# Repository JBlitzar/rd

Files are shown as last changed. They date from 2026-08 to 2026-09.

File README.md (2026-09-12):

# rd

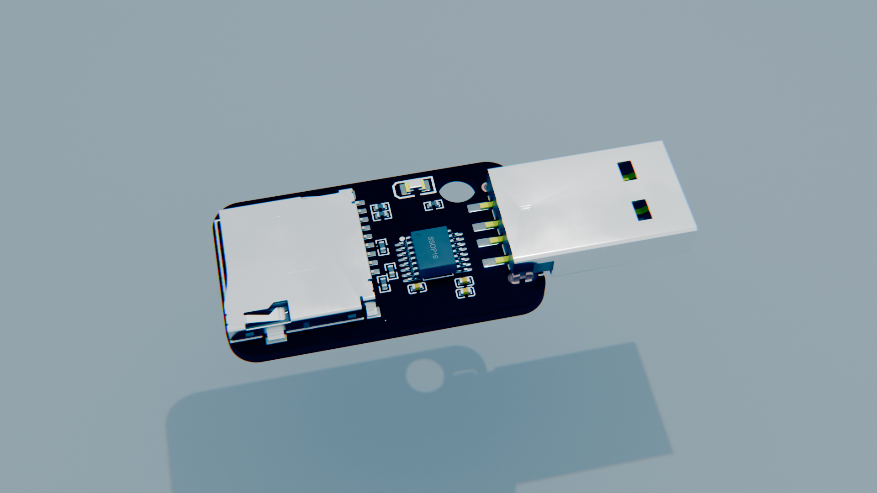
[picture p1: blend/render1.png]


microSD card reader. it exposes microSD cards as a block device that you can read and write to!

Features:
 - dead-simple schematic thanks to the GL823K chip
 - green status LED for activity
 - 4mm keychain hole
 - supports USB 2.0 HS and microSD HS. This means up to 25 MB/s ! 

I made this project because I needed a project scoped to be able to speedrun in 36 hours wall-clock and very little actual working time. It grants me utility-- this way I can read and write to microSD cards super easily in a small form factor, using a dongle I created!! I think microSD cards are uniquely very versatile. There are ones with industrially-rated durability. There are ones that go up to 2TB. There are ones that are so dirt-cheap they cost only a little bit more than the raw NAND inside them. Also, this project unlocks a new ASIC for me that I haven't used before.  

| |  |
| --- | --- |
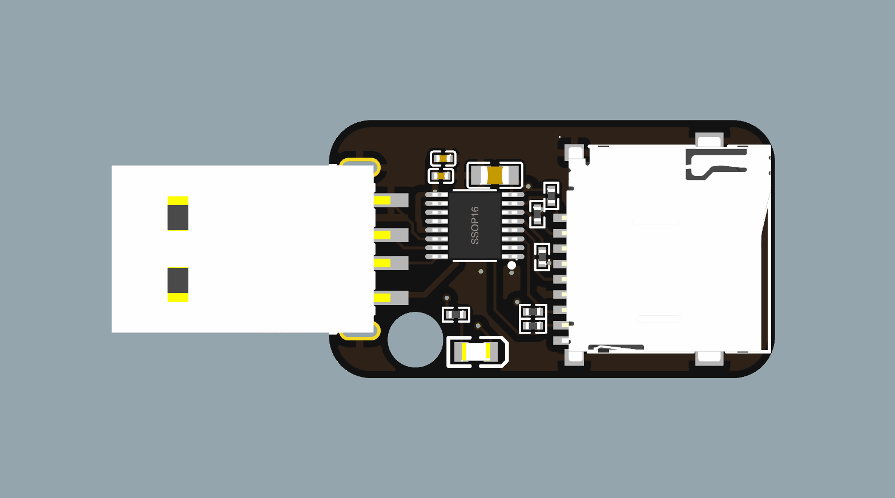
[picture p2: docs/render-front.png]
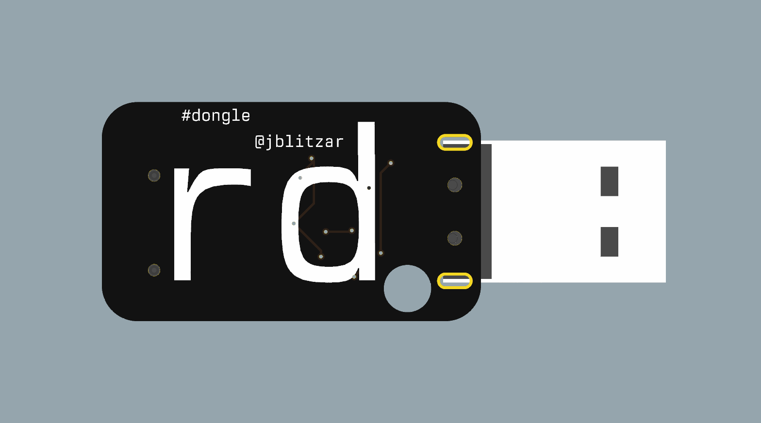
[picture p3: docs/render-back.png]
|  |  |

## Schematic

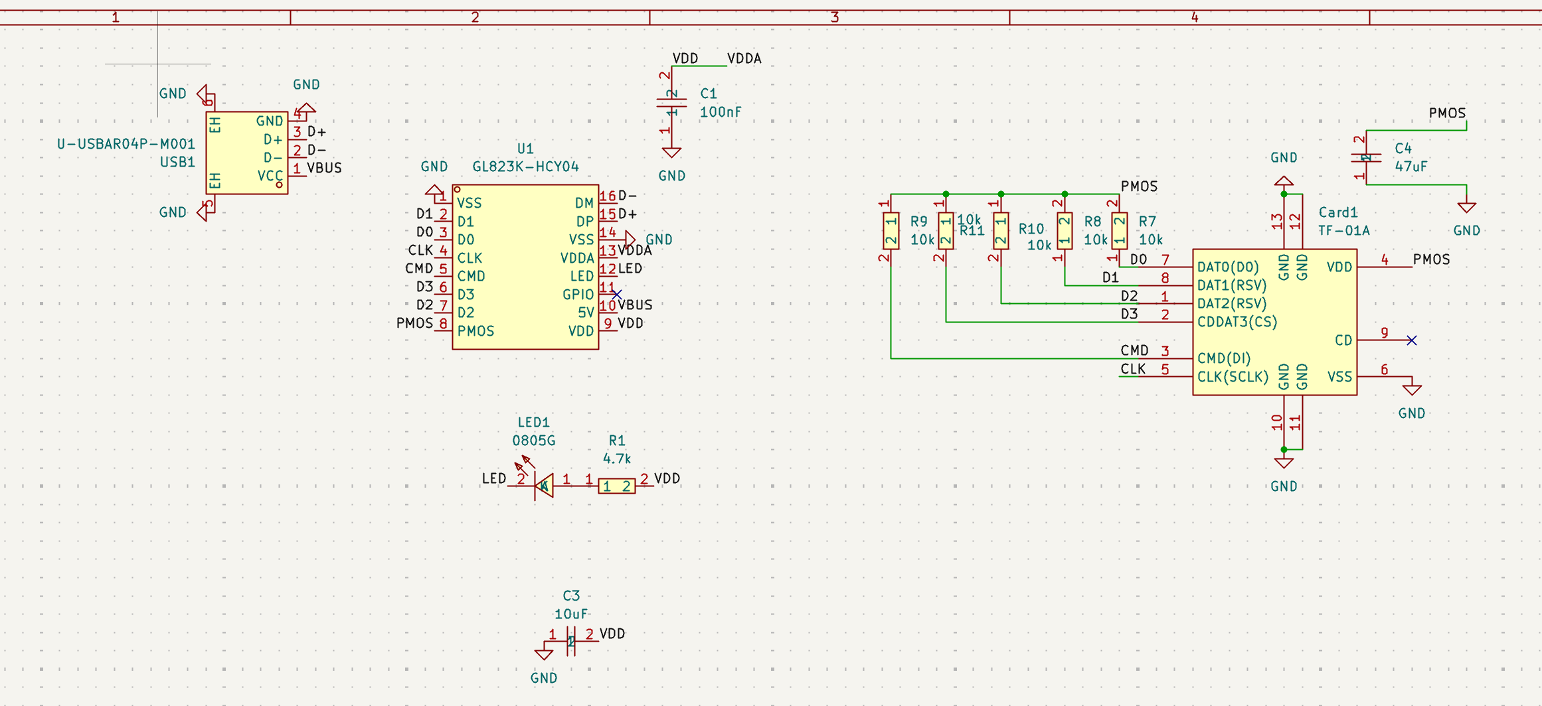
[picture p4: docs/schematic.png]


## PCB

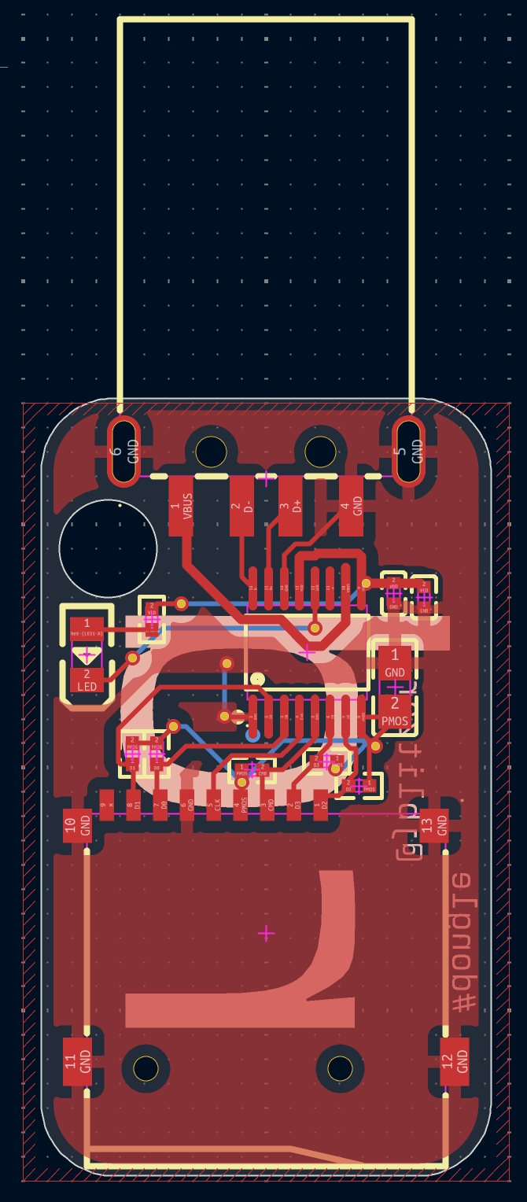
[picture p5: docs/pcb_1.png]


## Production outputs like gerbers

Find them in [PCB/rd/production](PCB/rd/production)!

## BOM

Order by uploading the fabrication outputs (linked above) to jlcpcb!

|Item |Cost |Notes |
|---|-----|---|
|5x PCB (MOQ) |2.0  |order off of JLCONE desktop to save two dollars instead of it costing $4|
|2x PCBA (MOQ)|24.15| |
|Shipping |3.3  |Shipping special offer, otherwise costs 7 |
|Total |29.45| |

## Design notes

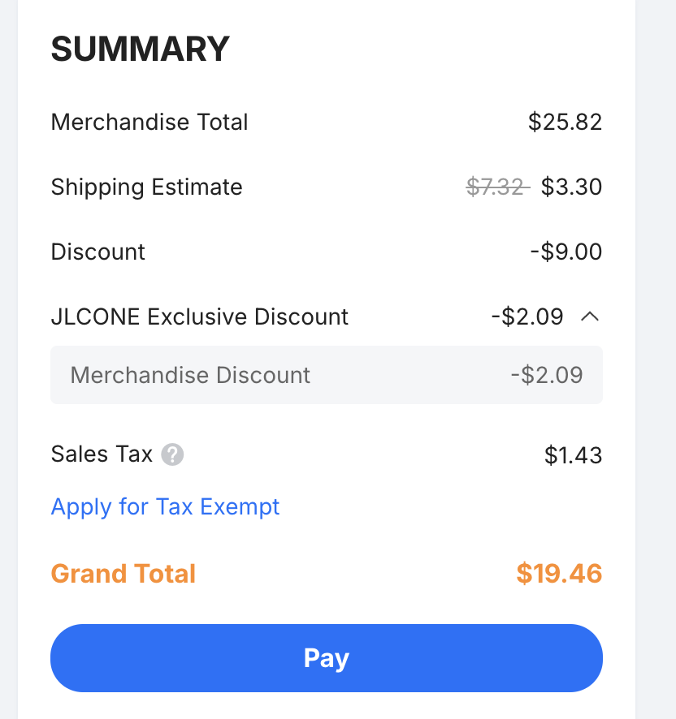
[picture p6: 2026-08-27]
docs/cart.png

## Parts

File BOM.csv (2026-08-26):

Item | Cost | Notes
5x PCB (MOQ) | 2.1 | order off of JLCONE desktop to save two dollars instead of it costing $4
2x PCBA (MOQ) | 23.82
Shipping | 3.3 | Shipping special offer, otherwise costs 7
Total | 29.22

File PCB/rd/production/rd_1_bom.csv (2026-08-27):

Designator | Footprint | Quantity | Value | LCSC Part #
C1 | C0402 | 1 | 100nF | C1525
C3 | C0402 | 1 | 10uF | C15525
C4 | C0805 | 1 | 47uF | C16780
CARD1 | TF-SMD_TF-01A | 1 | TF-01A | C91145
LED1 | LED0805-R-RD | 1 | 0805G | C2297
R1 | R0402 | 1 | 4.7k | C25900
R10, R11, R7, R8, R9 | R0402 | 5 | 10k | C25744
U1 | SSOP-16_L4.9-W3.9-P0.64-LS6.0-BL | 1 | GL823K-HCY04 | C284879
USB1 | USB-SMD_KH-USB-AM-4P-CB | 1 | U-USBAR04P-M001 | C386752

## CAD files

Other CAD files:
blend/rd.blend

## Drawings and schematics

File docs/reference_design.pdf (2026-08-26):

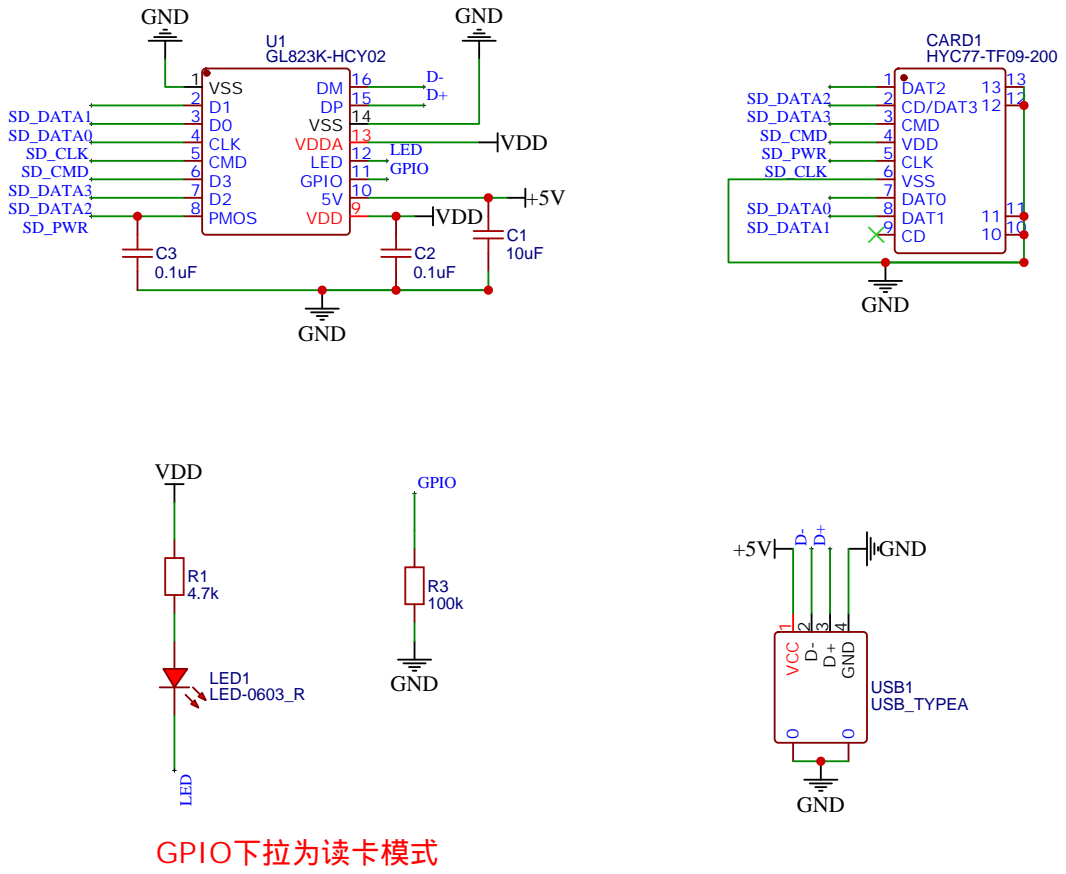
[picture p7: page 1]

GL823K-HCY02
5V 10 GPIO 11 LED 12 VDDA 13 VSS 14 DP 15 DM 16

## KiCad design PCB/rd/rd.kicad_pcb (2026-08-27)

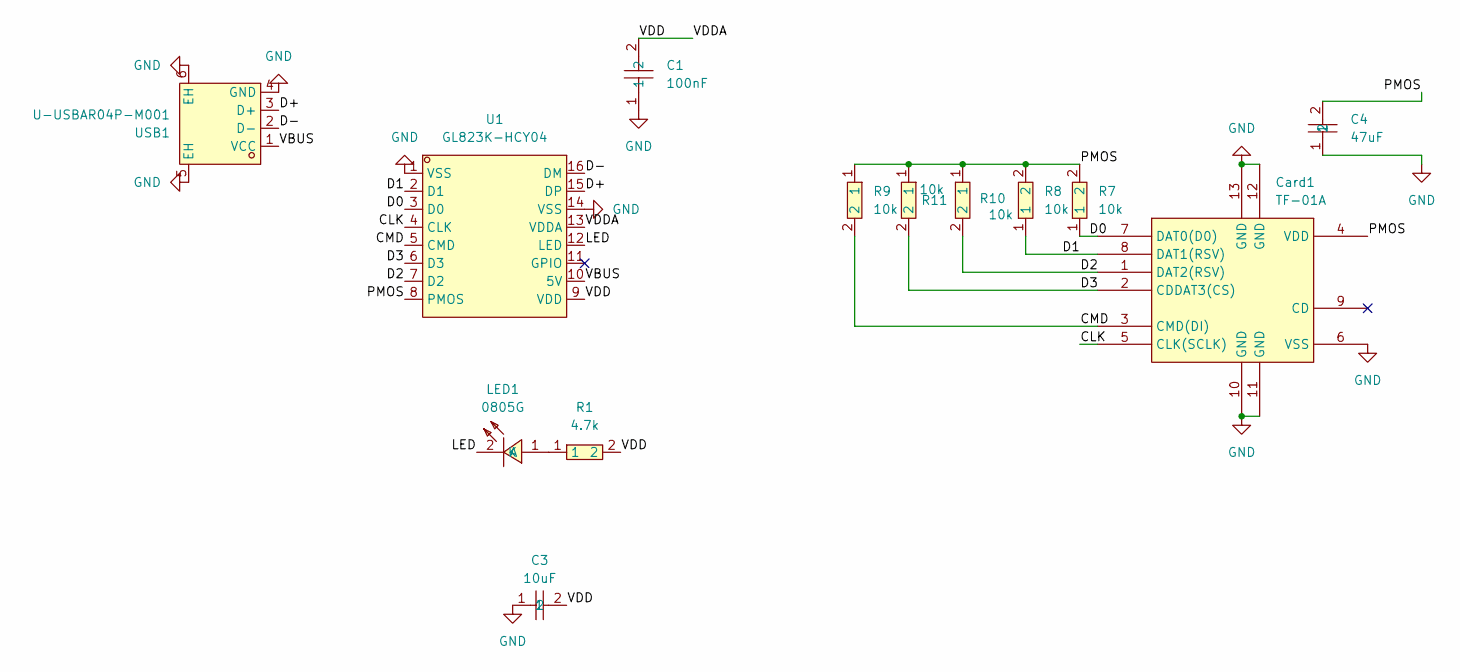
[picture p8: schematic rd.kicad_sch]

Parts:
C1: 100nF; C0402; MPN CL05B104KO5NNNC; LCSC Part C1525
C3: 10uF; C0402; MPN CL05A106MQ5NUNC; LCSC Part C15525
C4: 47uF; C0805; MPN CL21A476MQYNNNE; LCSC Part C16780
Card1: TF-01A; TF-SMD_TF-01A; MPN TF-01A; LCSC Part C91145
LED1: 0805G; LED0805-R-RD; MPN KT-0805G; LCSC Part C2297
R1: 4.7k; R0402; MPN 0402WGF4701TCE; LCSC Part C25900
R7, R8, R9, R10, R11: 10k; R0402; MPN 0402WGF1002TCE; LCSC Part C25744
U1: GL823K-HCY04; SSOP-16_L4.9-W3.9-P0.64-LS6.0-BL; MPN GL823K-HCY04; LCSC Part C284879
USB1: U-USBAR04P-M001; USB-SMD_KH-USB-AM-4P-CB; MPN U-USBAR04P-M003; LCSC Part C386752

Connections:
/CLK: Card1.5 (CLK(SCLK)), U1.4 (CLK)
/CMD: Card1.3 (CMD(DI)), R9.2, U1.5 (CMD)
/D0: Card1.7 (DAT0(D0)), R7.1, U1.3 (D0)
/D1: Card1.8 (DAT1(RSV)), R8.1, U1.2 (D1)
/D2: Card1.1 (DAT2(RSV)), R10.2, U1.7 (D2)
/D3: Card1.2 (CDDAT3(CS)), R11.2, U1.6 (D3)
/D+: U1.15 (DP), USB1.3 (D+)
/D-: U1.16 (DM), USB1.2 (D-)
/LED: LED1.2 (K), U1.12 (LED)
/PMOS: C4.2, Card1.4 (VDD), R7.2, R8.2, R9.1, R10.1, R11.1, U1.8 (PMOS)
/VBUS: U1.10 (5V), USB1.1 (VCC)
/VDD: C1.2, C3.2, R1.2, U1.9 (VDD), U1.13 (VDDA)
GND: C1.1, C3.1, C4.1, Card1.6 (VSS), Card1.10 (GND), Card1.11 (GND), Card1.12 (GND), Card1.13 (GND), U1.1 (VSS), U1.14 (VSS), USB1.4 (GND), USB1.5 (EH), USB1.6 (EH)
unnamed: LED1.1 (A), R1.1

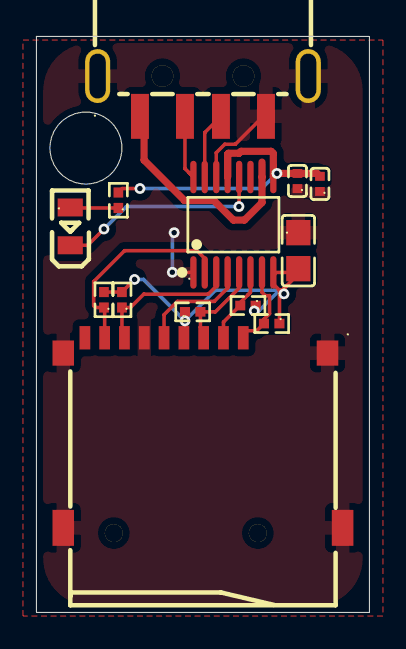
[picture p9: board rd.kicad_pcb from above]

Board: 2 copper layers, 18.5 x 32.0 mm, 13 parts (0 on the bottom side), 14 nets.

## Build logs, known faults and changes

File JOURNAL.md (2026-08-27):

# 25 August

Had this idea, did some research, and made the schematic super duper quickly.

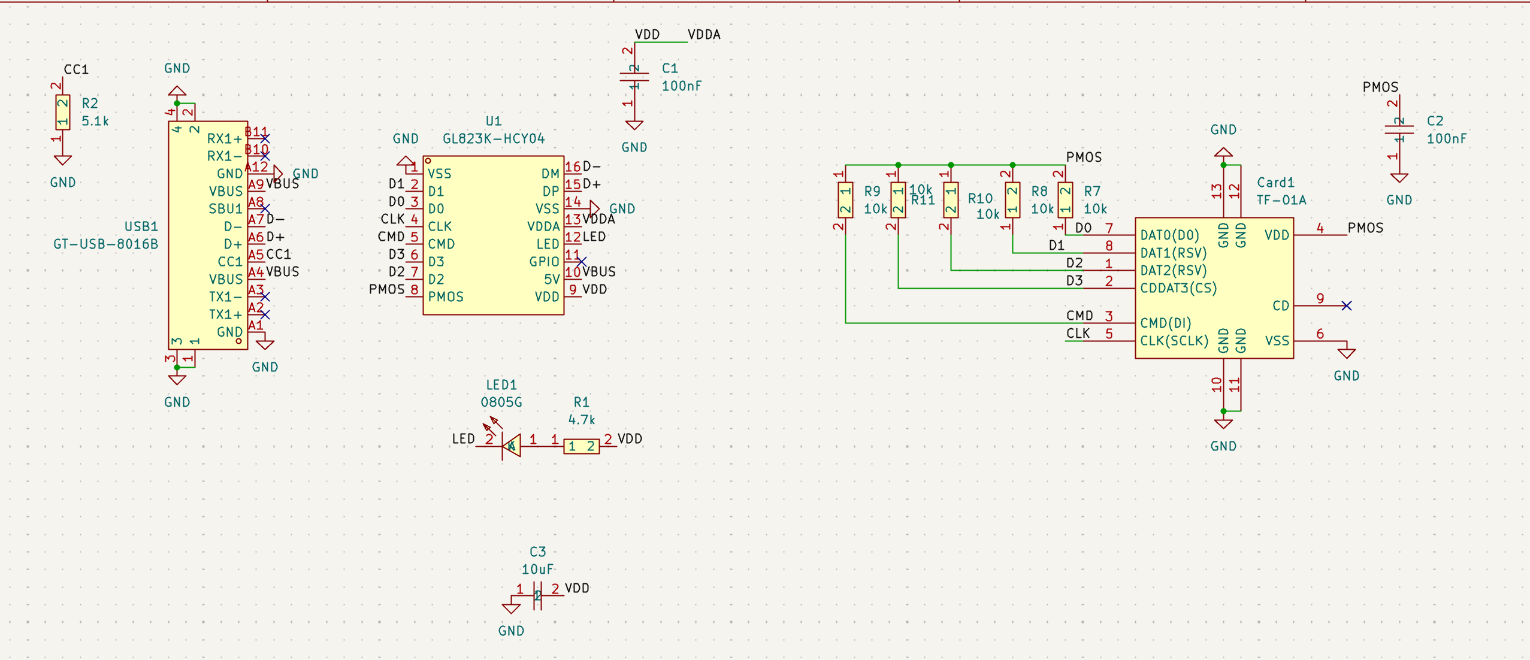
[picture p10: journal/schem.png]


Pinout is mostly self-explanatory, also found a sus reference design off of eeworld but its pretty sus bc they dont have pullups on the SD data lines. not sure if I should trust their cap values but they look plausible I guess lol. Also wanted to double check my LED direction with it

Time spent: 0.6 hours

# 25 August

Simple layout done

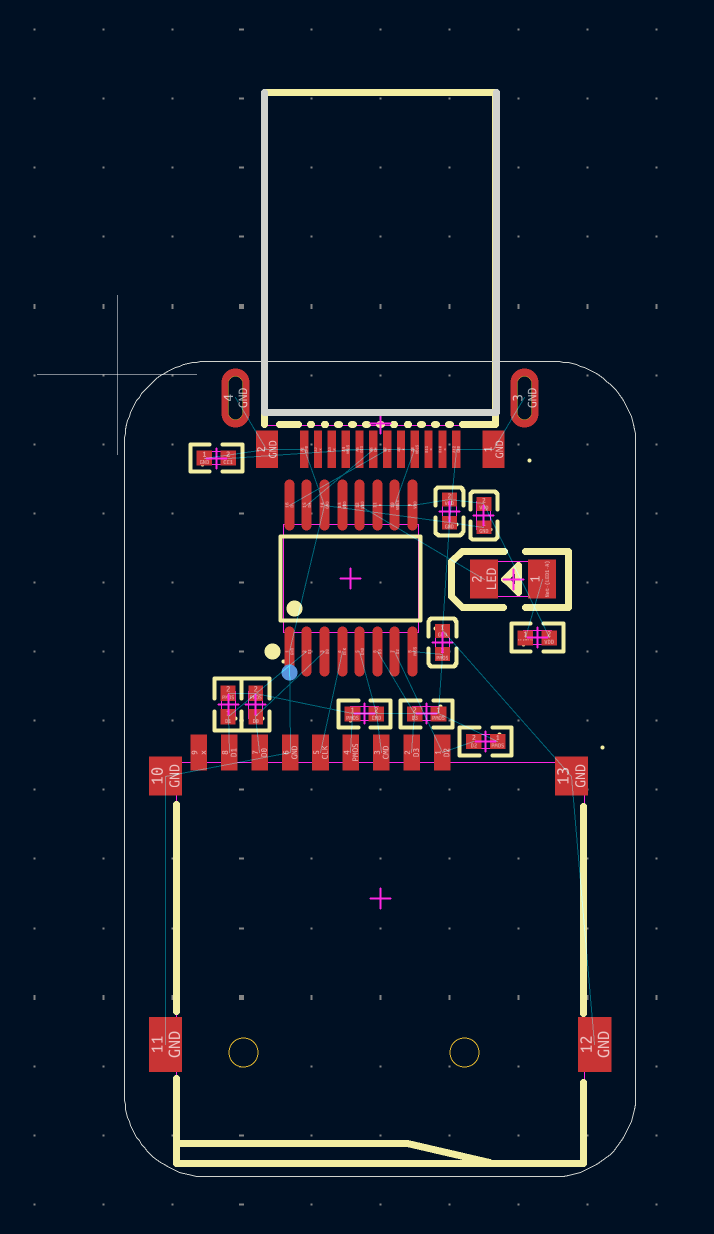
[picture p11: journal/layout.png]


tbd if the top usb bit is routable, but the SD is.

Time spent: 0.25 hours

# 26 August

Routed it, swapped to USB A because there are no good USB C male connectors. Use a dongle. It's okay.

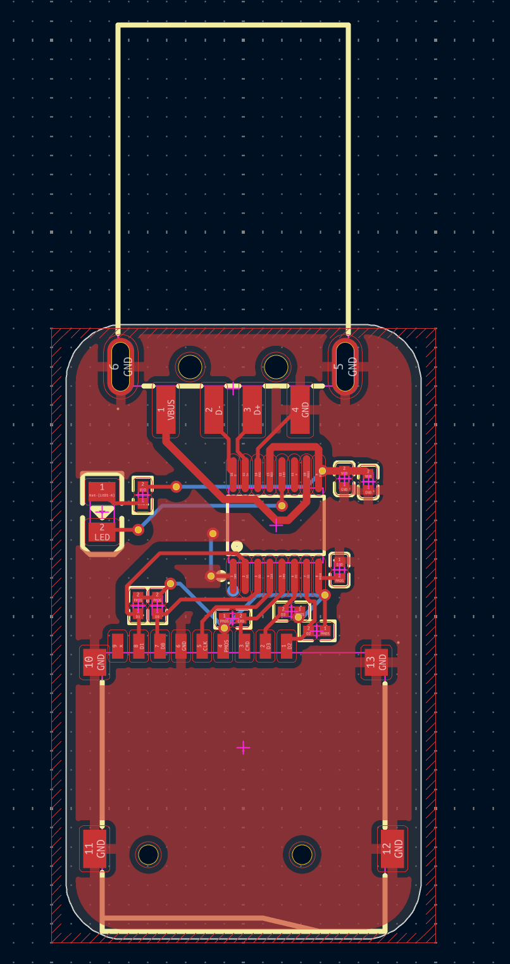
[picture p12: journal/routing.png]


Time spent: 0.2 hours

## 26 August

Got a quote and got the BOM. Had to rotate one thing.

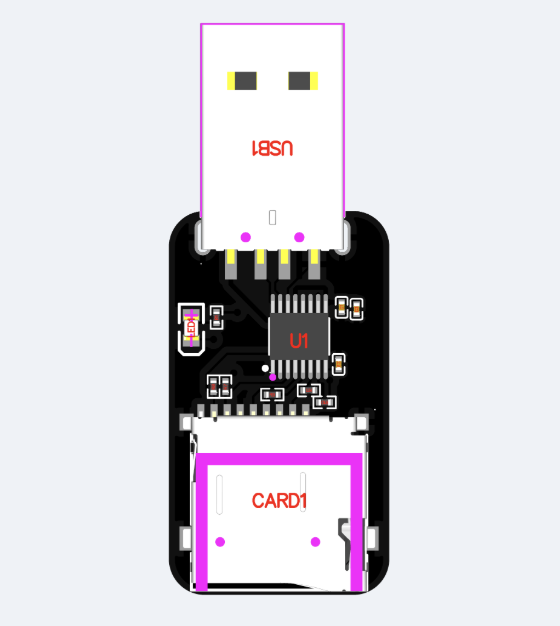
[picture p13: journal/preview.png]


I hope $29 is acceptable....

Time spent: 0.2 hours

## 26 August

Final touches. I did some stuff on the silkscreen (added my name and #dongle), re-exported everything, made a blender render (had to tweak compositing), re-quoted on JLCONE, and did a pass on the README! Finally the grand total is under $20 (barely lol) yayayayay!!

Investigated using an edge connector but it's not worth it. Worse fit, need to pay $30 more or do a case, etc etc. 

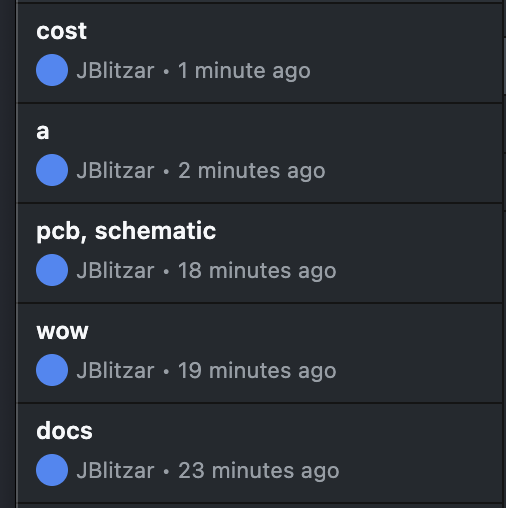
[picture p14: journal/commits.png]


I think I'm ready to submit!

Time spent: 0.3 hours

## 26 August

Emergency addition of 47uF cap as per peer advice. Eliminated the 100uF in tandem ([1](https://www.signalintegrityjournal.com/articles/1589-the-myth-of-three-capacitor-values))

Re-exported. Assumed the quote is $0.33 more all the way through after clicking through a bit. 19.79 still gets me barely under $20 !!

Time spent: 0.2 hours

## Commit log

2026-08-27 pcb, schematic
2026-08-27 emergency 47uF addition
    [rd.kicad_pcb, rd.kicad_sch, rd_1_bom.csv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]
